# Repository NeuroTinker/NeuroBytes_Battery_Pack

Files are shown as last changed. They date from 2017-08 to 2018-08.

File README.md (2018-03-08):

# NeuroBytes Battery Pack
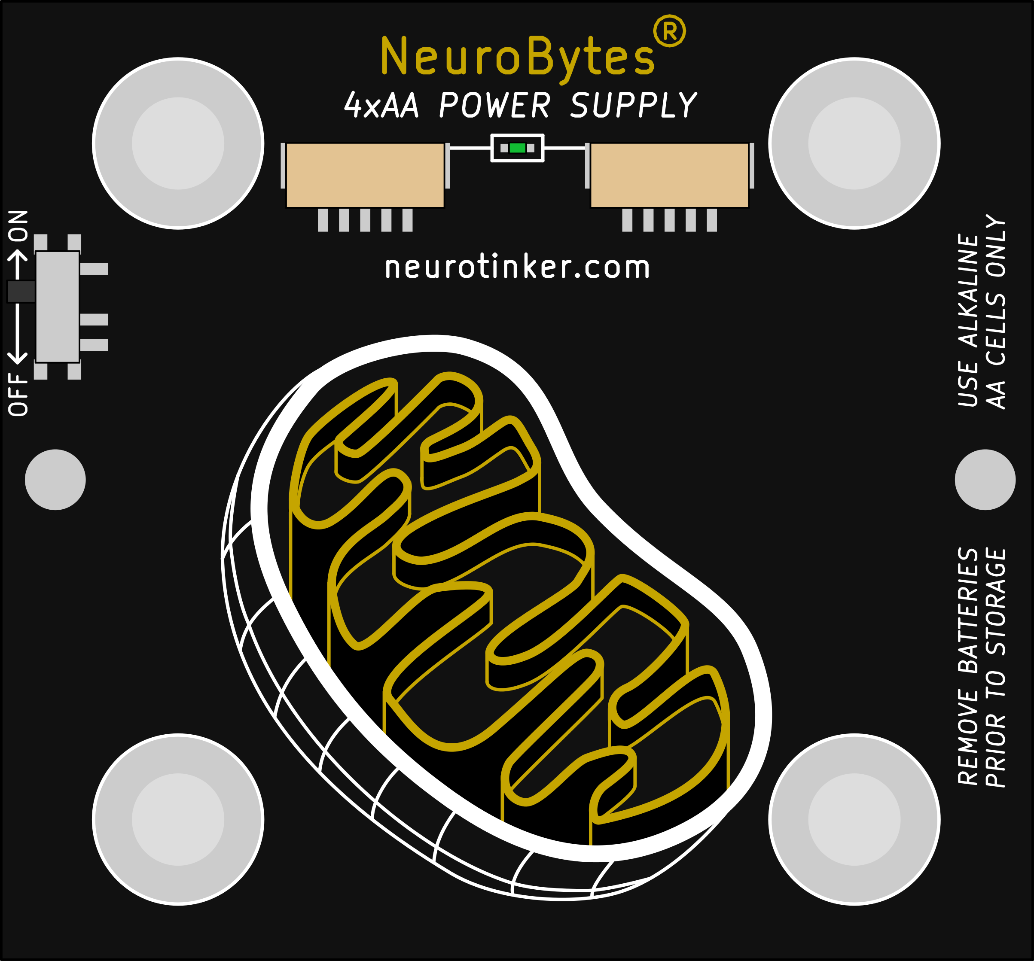
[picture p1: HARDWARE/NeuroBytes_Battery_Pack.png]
NeuroBytes Battery Pack PCB front

The NeuroBytes Battery Pack provides power to NeuroBytes products, open-source hardware neuron simulators designed and sold by [NeuroTinker, LLC](http://www.neurotinker.com/). Battery Packs feature a pair of power connections and a power switch with indicator LED, and require four alkaline AA batteries to operate.

These boards were designed in KiCad and Inkscape and are released under the terms of the Creative Commons Attribution-ShareAlike 4.0 license, available here: https://creativecommons.org/licenses/by-sa/4.0/. The NeuroBytes Battery Pack is Certified Open Source Hardware as defined by [OSHWA](https://www.oshwa.org), certification number US000114.


OSHWA Certification

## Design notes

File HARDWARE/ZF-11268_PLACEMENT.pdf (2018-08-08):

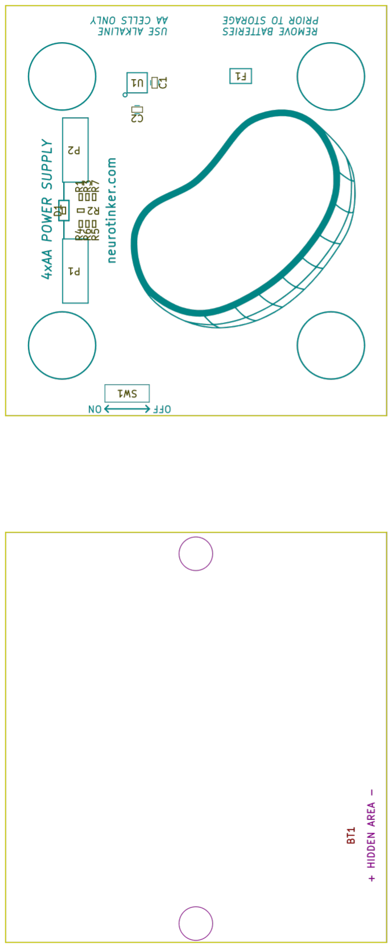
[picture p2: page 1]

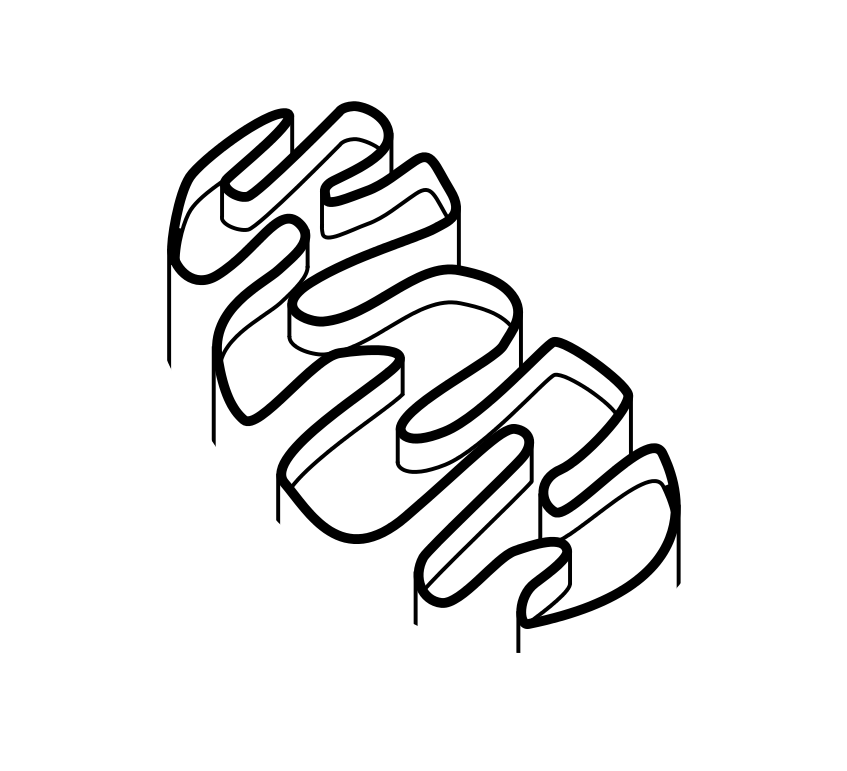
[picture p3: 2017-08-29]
HARDWARE/mitochondria_mask.png

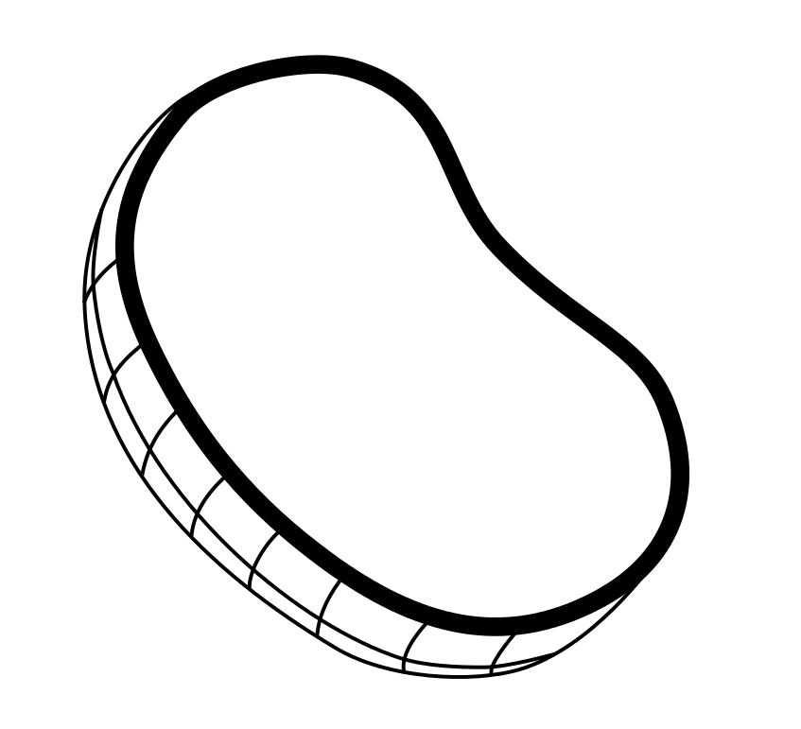
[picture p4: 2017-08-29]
HARDWARE/mitochondria_silk.png

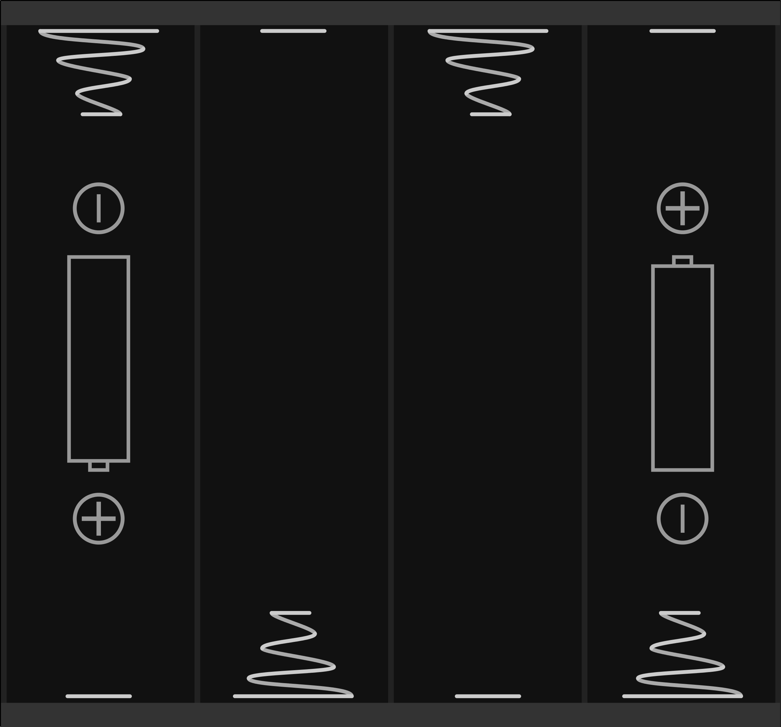
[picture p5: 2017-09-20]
HARDWARE/NeuroBytes_Battery_Pack_back.png

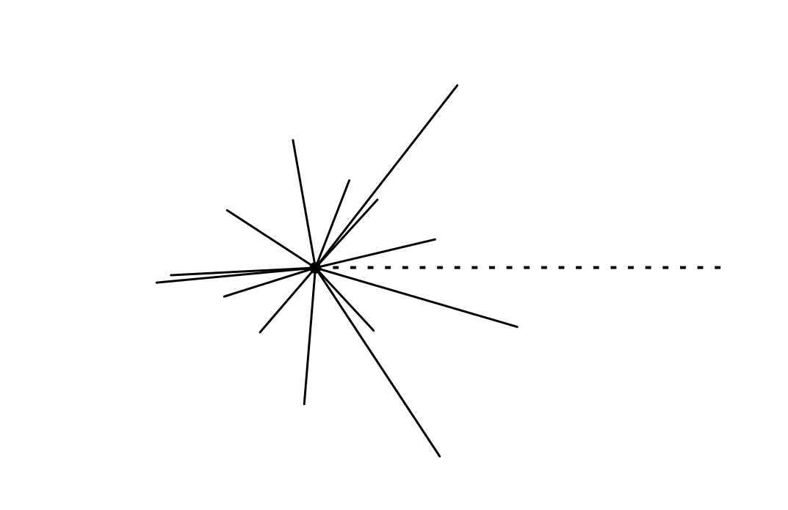
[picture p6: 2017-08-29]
HARDWARE/map.png

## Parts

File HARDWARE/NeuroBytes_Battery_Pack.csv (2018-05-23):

Ref | Qty | Value | Link | Mfr | Mfr Part # | Package | RoHS | Subs Allowed
BT1 | 1 | 4xAA | https://www.digikey.com/product-detail/en/mpd-memory-protection-devices/BC4AAPC/BC4AAPC-ND/2329366 | MPD (Memory Protection Devices) | BC4AAPC | THT | Yes | No
C1 C2 | 2 | 1u | https://www.digikey.com/product-detail/en/taiyo-yuden/LMK107B7105KA-T/587-1242-2-ND/930594 | Taiyo Yuden | LMK107B7105KA-T | C0603 | Yes | Yes
D1 | 1 | LED | https://www.digikey.com/product-detail/en/rohm-semiconductor/SMLP13EC8TT86/846-1113-2-ND/3973665 | Rohm Semiconductor | SMLP13EC8TT86 | L0402 | Yes | No
F1 | 1 | 500 mA | https://www.digikey.com/product-detail/en/bel-fuse-inc/0ZCH0050FF2G/507-1786-2-ND/4156298 | Bel Fuse Inc. | 0ZCH0050FF2G | F1210 | Yes | Yes
P1 P2 | 2 | JST_GH_5-pos | https://www.digikey.com/product-detail/en/jst-sales-america-inc/SM05B-GHS-TB-LF-SN/455-1567-2-ND/807789 | JST | SM05B-GHS-TB(LF)(SN) | SMT | Yes | No
R2 | 1 | 4k7 | https://www.digikey.com/product-detail/en/yageo/RC0402FR-074K7L/311-4.7KLRCT-ND/2827881 | Yageo | RC0402FR-074K7L | R0402 | Yes | Yes
R4 R5 R6 R1 R3 R7 | 6 | 10k | https://www.digikey.com/product-detail/en/yageo/RC0402FR-0710KL/311-10.0KLRTR-ND/726523 | Yageo | RC0402FR-0710KL | R0402 | Yes | Yes
SW1 | 1 | Switch_SPDT | https://www.digikey.com/product-detail/en/c-k/PCM12SMTR/401-2016-1-ND/1640125 | C&K | PCM12SMTR | SMT | Yes | No
U1 | 1 | LDL212_LDO | https://www.digikey.com/product-detail/en/stmicroelectronics/LDL212PU50R/497-16897-1-ND/6230213 | ST Microelectronics | LDL212PU50R | 6DFN | Yes | No
BOM made with KICAD_BOM_WIZARD (https://github.com/HashDefineElectronics/KiCad_BOM_Wizard.git)
Generated Wed 23 May 2018 01:54:09 PM CDT

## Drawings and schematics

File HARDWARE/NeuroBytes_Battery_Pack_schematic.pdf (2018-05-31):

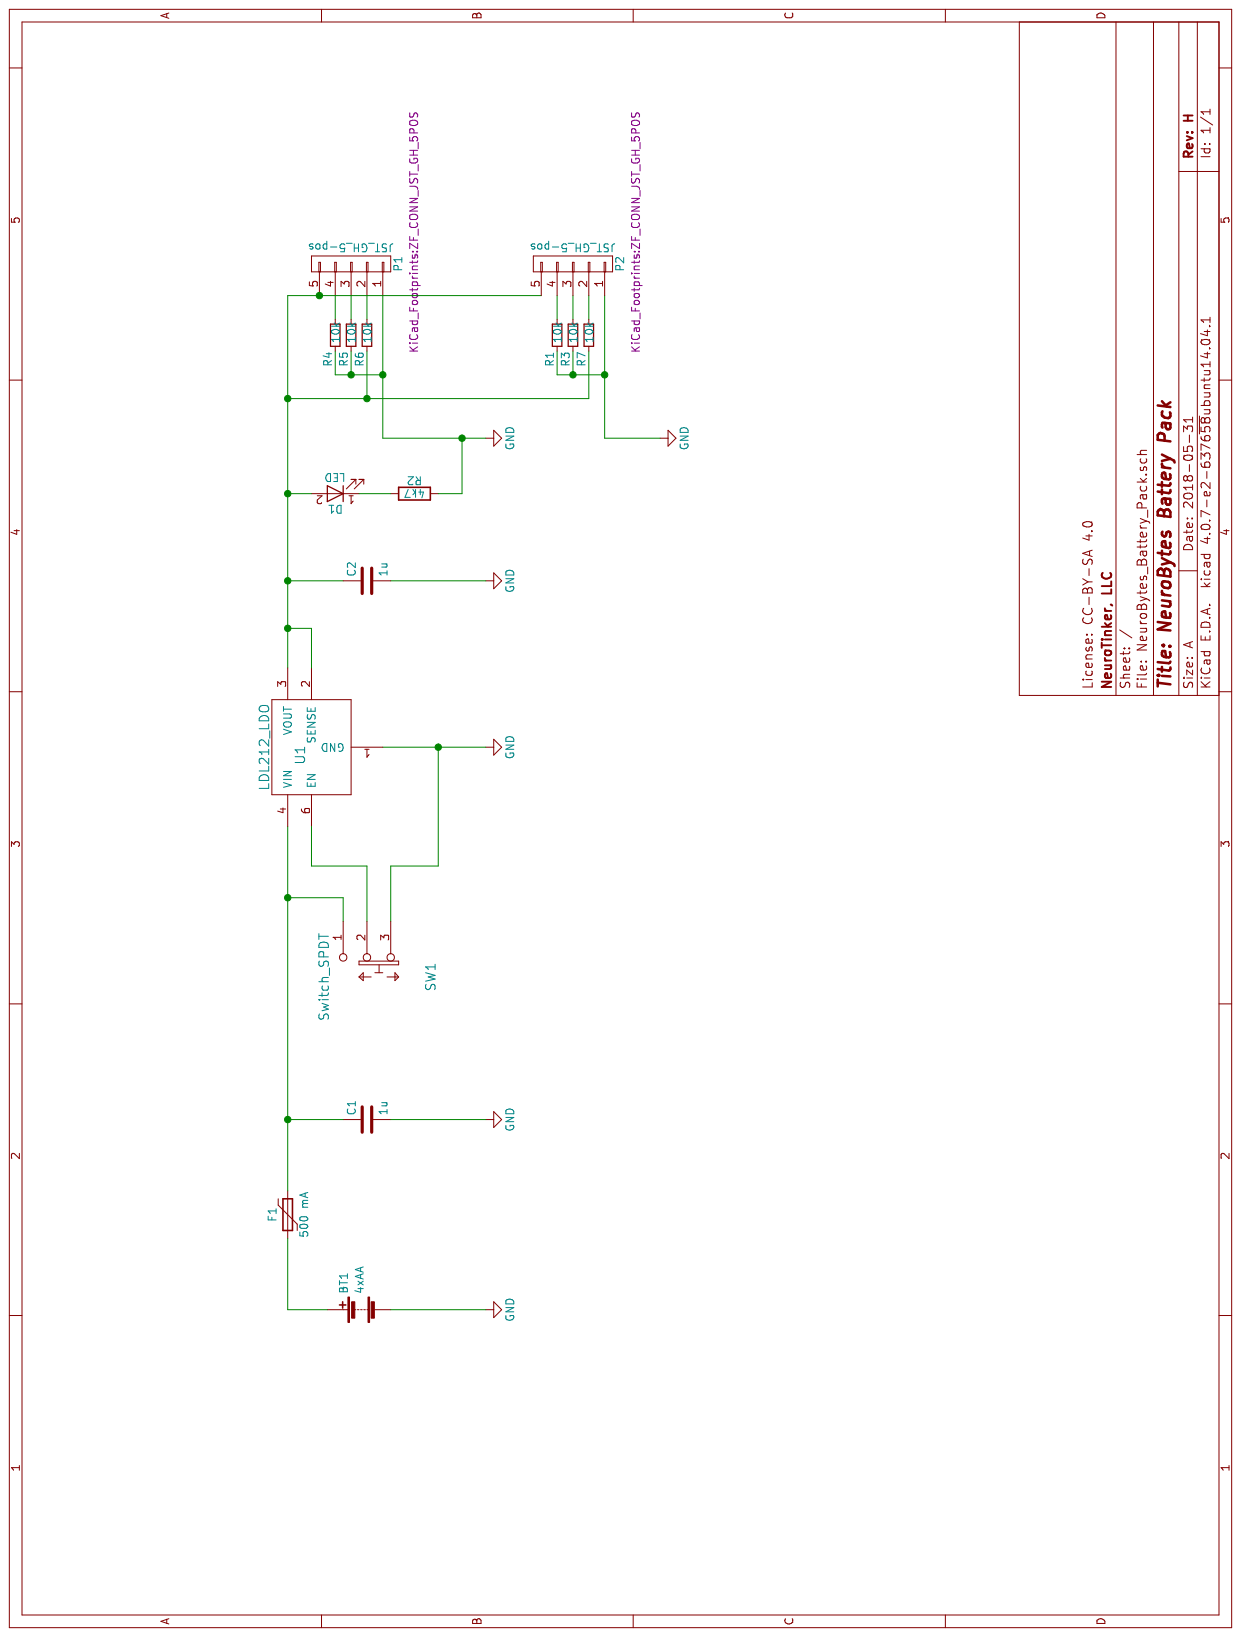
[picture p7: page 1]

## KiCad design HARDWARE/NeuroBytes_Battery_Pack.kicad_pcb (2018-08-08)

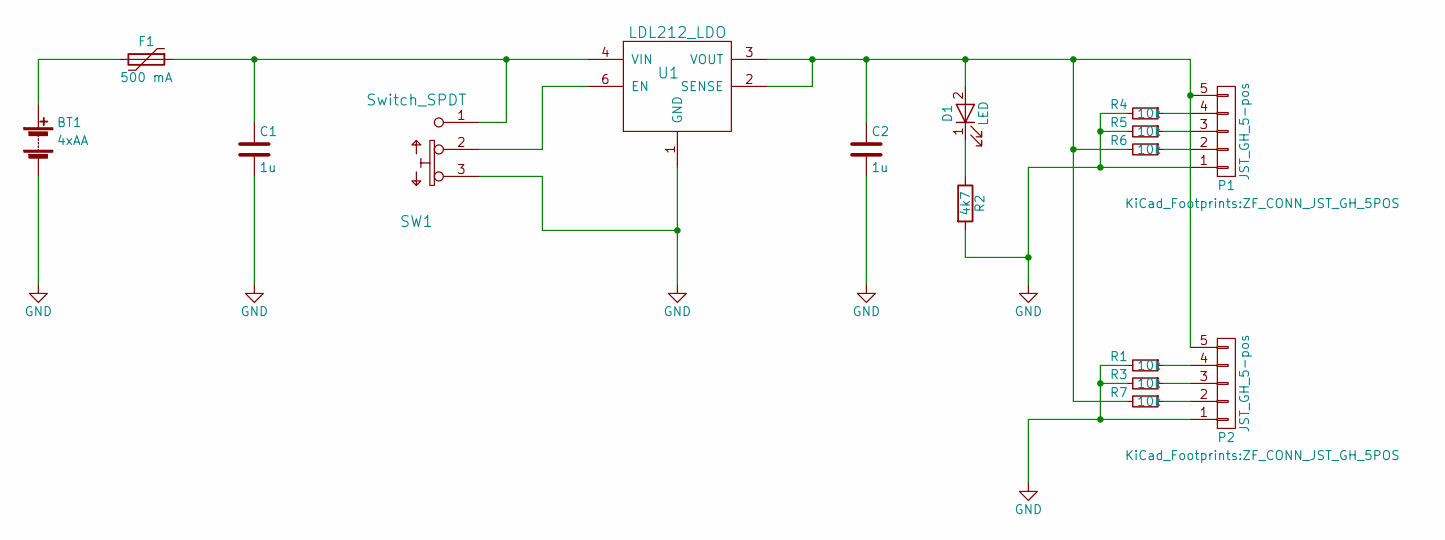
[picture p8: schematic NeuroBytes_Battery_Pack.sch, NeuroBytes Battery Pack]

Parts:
BT1: 4xAA; ZF_BATT_4xAA_BC4AAPC; Mfr Part # BC4AAPC
C1, C2: 1u; C_0603_HandSoldering; Mfr Part # LMK107B7105KA-T
D1: LED; ZF_SMD_NonPol_0402; Mfr Part # SMLP13EC8TT86
F1: 500 mA; ZF_SMD_nonpol_1210; Mfr Part # 0ZCH0050FF2G
P1, P2: JST_GH_5-pos; ZF_CONN_JST_GH_5POS; Mfr Part # SM05B-GHS-TB(LF)(SN)
R1, R3, R4, R5, R6, R7: 10k; ZF_SMD_NonPol_0402; Mfr Part # RC0402FR-0710KL
R2: 4k7; ZF_SMD_NonPol_0402; Mfr Part # RC0402FR-074K7L
SW1: Switch_SPDT; ZF_SW_PCM12SMTR; Mfr Part # PCM12SMTR
U1: LDL212_LDO; ZF_IC_DFN6_3x3; Mfr Part # LDL212PU50R

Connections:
GND: BT1.2 (-), C1.2, C2.2, P1.1, P2.1, R1.2, R2.2, R3.2, R4.2, R5.2, SW1.3, U1.1 (GND)
unnamed: BT1.1 (+), F1.2
unnamed: C1.1, F1.1, SW1.1, U1.4 (VIN)
unnamed: C2.1, D1.2 (A), P1.5, P2.5, R6.2, R7.2, U1.2 (SENSE), U1.3 (VOUT)
unnamed: D1.1 (K), R2.1
unnamed: P1.2, R6.1
unnamed: P1.3, R5.1
unnamed: P1.4, R4.1
unnamed: P2.2, R7.1
unnamed: P2.3, R3.1
unnamed: P2.4, R1.1
unnamed: SW1.2, U1.6 (EN)

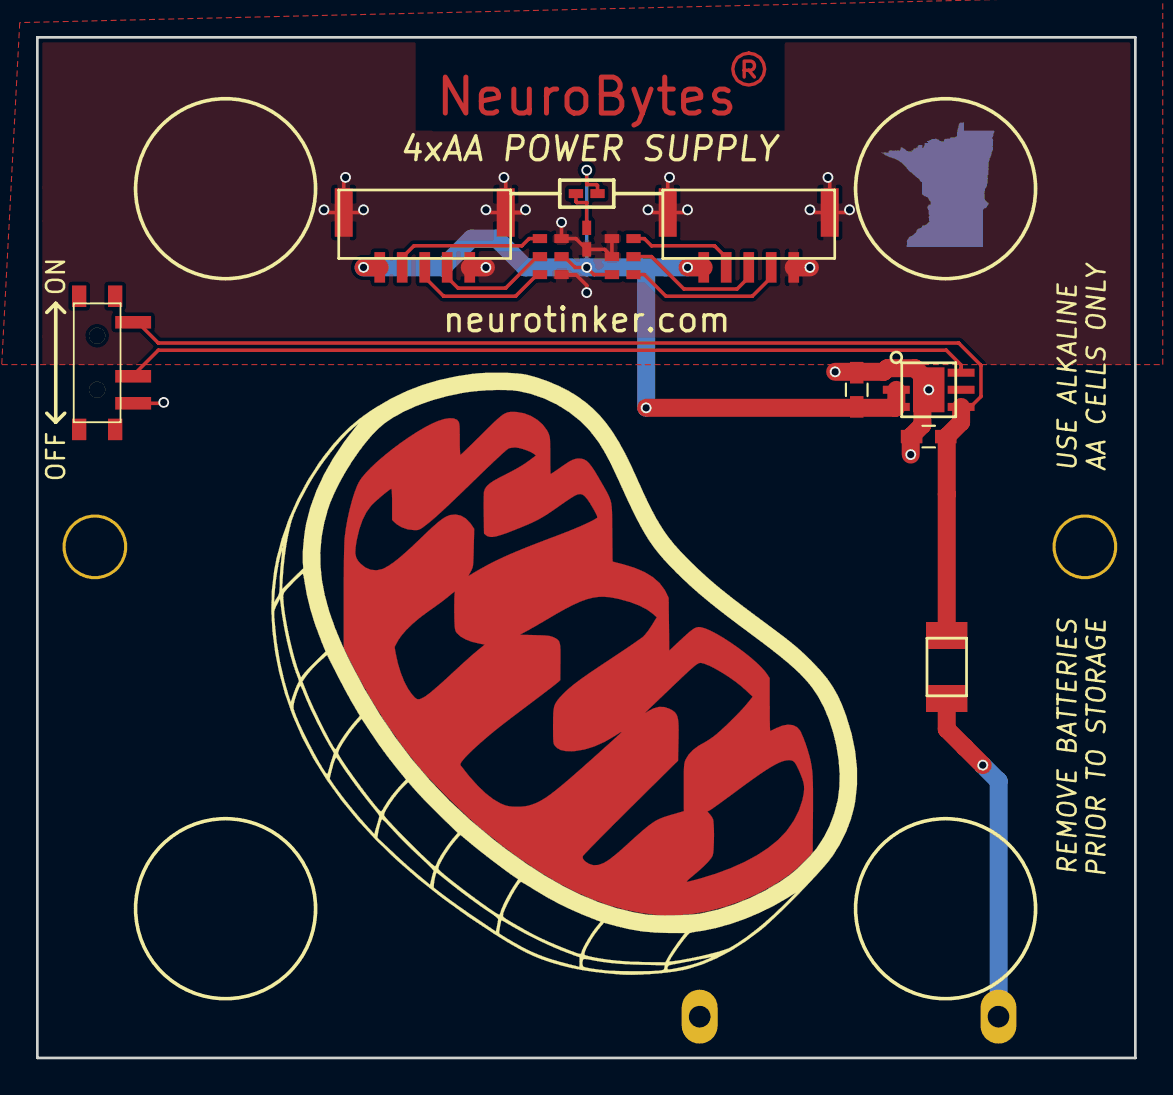
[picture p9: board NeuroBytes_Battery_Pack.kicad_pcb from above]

Board: 2 copper layers, 61.0 x 56.7 mm, 16 parts (1 on the bottom side), 12 nets.

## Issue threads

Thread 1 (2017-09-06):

Update hardware to include two battery connections (as seen in current *.png renders)

zakqwy, 2017-09-06:

zakqwy, 2017-09-19:
updated (waiting on new board spin), also changed switch to low-profile side mtg version. moved led.

Closed 2017-09-19.

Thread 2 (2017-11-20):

replace PMIC with schottky diode

zakqwy, 2017-11-20:

zakqwy, 2017-11-29:
this issue should have been on the NID, oops. closing.

Closed 2017-11-29.

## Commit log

2017-08-29 pulled in battery pack design files from previous repo. 'first' commit.
    [NeuroBytes_Battery_Pack.kicad_pcb, NeuroBytes_Battery_Pack.sch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]
2017-09-19 updated to include two 5-pin JST connectors and side-mtg switch. Moved LED to center.
    [NeuroBytes_Battery_Pack.kicad_pcb, NeuroBytes_Battery_Pack.sch]
2017-09-20 updated graphics to reflect new switch and dual-output PCB
2017-09-20 updated *.png exports to reflect new connector location and switch style
2017-10-04 updated component labels and regenerated netlist. generated BOM. minor page layout updates.
    [NeuroBytes_Battery_Pack.csv, NeuroBytes_Battery_Pack.kicad_pcb, NeuroBytes_Battery_Pack.sch]
2017-11-29 updated license and readme. added drawing number and license to PCB layout drawing.
    [NeuroBytes_Battery_Pack.kicad_pcb]
2018-05-23 generated BOM and fab files
    [NeuroBytes_Battery_Pack-B.Cu.gbr, NeuroBytes_Battery_Pack-B.Mask.gbr, NeuroBytes_Battery_Pack-B.Paste.gbr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]
2018-05-23 updated INSERT attribute and regenerated position file
    [NeuroBytes_Battery_Pack.kicad_pcb]
2018-05-31 updated schematic license and sheet size. added schematic pdf.
    [NeuroBytes_Battery_Pack.sch]
2018-07-20 added copper fill and via stitching around JST GH structural pads
    [NeuroBytes_Battery_Pack.kicad_pcb]
2018-08-08 updated footprints to include outlines. re-generated Gerbers. added placement pdf.
    [NeuroBytes_Battery_Pack-B.Cu.gbr, NeuroBytes_Battery_Pack-B.Fab.gbr, NeuroBytes_Battery_Pack-B.Mask.gbr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]
2018-08-08 regen drill file
    [NeuroBytes_Battery_Pack.drl]

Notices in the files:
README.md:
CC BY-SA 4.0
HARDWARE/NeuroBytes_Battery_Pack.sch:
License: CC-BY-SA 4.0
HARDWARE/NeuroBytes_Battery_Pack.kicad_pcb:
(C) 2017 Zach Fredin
